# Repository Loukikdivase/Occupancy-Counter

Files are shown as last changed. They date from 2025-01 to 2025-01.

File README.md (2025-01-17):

# Occupancy Counter

by: Loukik-Sachin Divase, Rudy Marvyn Kalisetty-Appadu

**Faculty of Technology and Bionics**

***Rhine-Waal University of Applied Sciences***

Date: 16 January 2025

----

## Abstract

The occupancy counter is designed to ensure a seamless flow of people, especially on a busy day. The system tracks the number of people entering and exiting a room and can be used for libraries, offices, toilets, labs, and more. It features real-time monitoring, status indication using LEDs, compliance with safety regulations, and energy-efficient operation. A microcontroller with IR sensors detects directional movement, updates the LCD display accordingly.

## Table of Contents

- [Abstract](#abstract)
- [1 Introduction](#1-introduction)
- [2 Theory](#2-theory)
- [3 Methodology](#3-methodology)
  - [3.1 Hardware](#31-hardware)
  - [3.2 Software](#32-software)
- [4 Bill of Materials (BOM)](#4-bill-of-materials-bom)
- [5 Results](#5-results)
  - [5 Prototype](#50-prototype)
  - [5.1 Schematic](#51-schematic)
  - [5.2 Board](#52-board)
  - [5.3 UV Masking](#53-uv-masking)
  - [5.4 Etching](#54-etching)
  - [5.5 Drilling](#55-drilling)
  - [5.6 Baking](#56-baking)
  - [5.7 Testing](#57-testing)
  - [5.8 Outsourcing](#58-outsourcing)
- [6 Discussion](#6-discussion)
- [7 Conclusion](#7-conclusion)
- [8 Power Consumption](#8-power-consumption)
- [9 References](#9-references)

## 1 Introduction

Managing space efficiently in crowded environments can be challenging. The people counter helps address this issue by providing real-time tracking of room occupancy.

## 2	Theory

The occupancy counter relies on IR sensors to detect movement direction. The system uses logic to determine whether a person enters or exits, ensuring accurate count tracking. If a person passes through sensor 1(placed outside the room near the door) and sensor 2(placed inside the room near the door), the sensor will count. The sensor will increase the count by 1 if a person passes sensor 1 before sensor 2. The sensor will decrease the count by 1 if the person passes sensor 2 before sensor 1.

## 3	Methodology

### 3.1 Hardware

The system consists of:  
•	Microcontroller (ATmega328p)   
•	16MHz Crystal Oscillator  
•	Infrared LED and photodiode  
•	LCD display (16x2)  
•	Buzzer    
•	LED indicators (Red/Green/Yellow)   
•	battery  
•	Voltage regulator (LM7805)   
•	Dual Comparator (LM393)  
•	resistors  
•	capacitors  
•	inductor  
•	switches  

### 3.2 Software

•	Notepad++ for writing the main program  
•	myAVRboard MK2 for flashing the ATmega328p microcontroller  
•	The program tracks occupancy using IR sensor logic and updates the display accordingly.  

#### Code Snippets

//Reset lock for sensor 1 when signal goes HIGH  

if (sensor1_state && sensor1_locked)  
{  
     sensor1_locked = 0; //Reset lock  
}
            
//Reset lock for sensor 2 when signal goes HIGH  

if (sensor2_state && sensor2_locked)  
{  
     sensor2_locked = 0;  // Reset lock  
}  

## 4 BOM

| No. | Qty. | Manufacturer | Component | Ordering Code (Manufacturer) | Vendor | Ordering Code (Vendor) | Price per Unit (€) | Price (€) | Link |
|----|----|---|---|---|---|---|---|---|---|
| 1  | 1  | Texas Instruments | 5V Voltage Regulator SMD | LM7805MPX/NOPB | Mouser | 595-LM7805MPX/NOPB | 1.31 | 1.31 | [Link](https://www.mouser.de/ProductDetail/Texas-Instruments/LM7805MPX-NOPB?qs=gO6GG99qvRCSwIVAoVKHPw%3D%3D) |
| 2  | 4  | Atmel | ATmega328P-PU S | - | HSRW | 1712 | 2.51 | 2.51 |  |
| 3  | 4  | - | 16MHz Crystal Oscillator | QD LFXTALO03240 | Reichelt | - | 0.43 | 0.43 | [Link](https://www.reichelt.de/standardquarz-grundton-16-mhz-iqd-lfxtal003240-p245409.html?&trstct=pos_0&nbc=1) |
| 4  | 2  | - | 22pF Capacitor | RND 150MT15N2202 | Reichelt | - | 0.02 | 0.04 | [Link](https://www.reichelt.de/smd-kerko-0402-22-pf-16-v-1-mlec-rnd-150mt15n2202-p225449.html?&trstct=pos_4&nbe=1) |
| 5  | 4  | - | 10k Ohm Resistor | - | HSRW | 621 | 0.01 | 0.04 | [Link](https://ee.hsrw.org/) |
| 6  | 2  | Vishay/BC Components | 220uF Capacitor, 10V DC | MAL214097403E3 | Mouser | 594-MAL214097403E3 | 1.97 | 3.94 | [Link](https://www.mouser.de/ProductDetail/Vishay-BC-Components/MAL214097403E3?qs=aJI9t0tCUIVP9cSclwINCQ%3D%3D) |
| 7  | 5  | - | LEDs | - | HSRW | 471,497,498 | 0.06 | 0.24 | [Link](https://ee.hsrw.org/) |
| 8  | 7  | - | 220 Ohm Resistor | - | HSRW | 579 | 0.01 | 0.07 | [Link](https://ee.hsrw.org/) |
| 9  | 1  | - | LCD Display 16x2 | DEBO LCD16X2 BL | Reichelt | - | 4.65 | 4.65 | [Link](https://www.reichelt.de/entwicklerboards-display-16-x-2-zeichen-blau-debo-led16x2-bl-p335002.html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) |
| 10 | 1  | - | 28-Pin IC Socket | - | HSRW | 630 | 0.21 | 0.21 | [Link](https://ee.hsrw.org/) |
| 11 | 2  | - | Push Button | TASTER 9305 | Reichelt | - | 0.20 | 0.40 | [Link](https://www.reichelt.de/kurzhubtaster-6x6mm-hoehe-8-Omm-12v-vertikal-taster-9305-p44586.html) |
| 12 | 2  | Everlight | Infrared Diode (940nm, emitter) | IR 7373C EVL | Reichelt | - | 0.15 | 0.30 | [Link](https://www.reichelt.de/infrarot-diode-gaalas-940-nm-50-5-mm-t-1-3-4-ir-7373c-evl-p219706.html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) |
| 13 | 6  | - | 0.1µF Capacitor SM | 0.1/63RAD | HSRW | 372 | 0.03 | 0.18 | [Link](https://ee.hsrw.org/) |
| 14 | 2  | Vishay | Phototransistor (Receiver) | BPV10NF | Reichelt | - | 0.35 | 0.70 | [Link](https://www.reichelt.de/pin-fotodiode-5mm-tageslichfilter-20-60-a-870-950nm-bpv-10nf-p146650.html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) |
| 15 | 4  | Aragonesa de Components | Potentiometer (10k Ohm) | ACP 6-S 10K | Reichelt | - | 0.21 | 0.84 | [Link](https://www.reichelt.de/einstellpotentiometer-stehend-10-kohm-6-mm-acp-6-s-10k-p110242.html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) |
| 16 | 1  | STMicroelectronics | LM393 Comparator | LM393 D STM | Reichelt | - | 0.21 | 0.21 | [Link](https://www.reichelt.de/komparator-18v-36v-2-fach-so-8-lm-393-d-stm-p348702.html?&trstct=pos_O&nbe=1) |
| 17 | 1  | - | 2-Pin Angled Connector (Male) | PSS 254/3W | Reichelt | - | 0.06 | 0.06 | [Link](https://www.reichelt.de/printstecker-einzelstecker-gewinkelt-3-polig-pss-254-3w-p14910.html) |
| 18 | 1  | OURNS | 10µH Inductor, 10% Tolerance | CC453232A-100KL | Mouser | 652-CC453232A-100KL | 0.47 | 0.47 | [Link](https://www.mouser.de/ProductDetail/Bourns/CC453232A-100KL?qs=sPbYRqrBIVk4tmhOTVDWBA%3D%3D) |
| 19 | 1  | - | Battery | - | HSRW | - | 1.00 | 1.00 | [Link](https://ee.hsrw.org/) |
| 20 | 1  | - | 3-Pin Switch | - | HSRW | - | 1.35 | 1.35 | [Link](https://ee.hsrw.org/) |
| 21 | 1  | - | Male Headers | - | HSRW | - | 1.00 | 1.00 | [Link](https://ee.hsrw.org/) |
| 22 | 1  | - | Buzzer | - | HSRW | - | 0.50 | 0.50 | [Link](https://ee.hsrw.org/) |
| 23 | 1  | - | NPN Transistor BC547 | - | HSRW | - | 0.36 | 0.36 | [Link](https://ee.hsrw.org/) |

## 5	Results

### Prototype

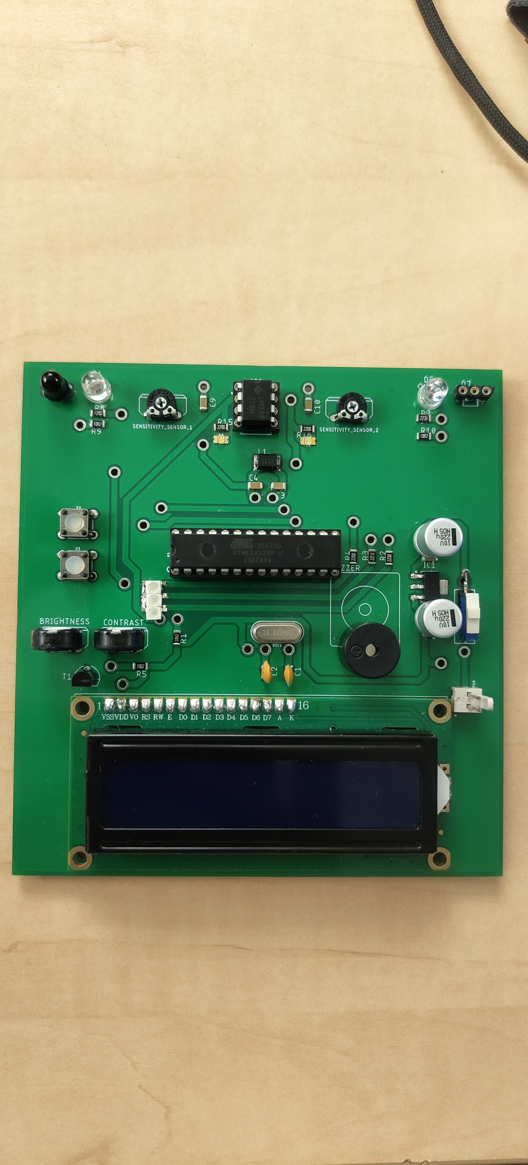
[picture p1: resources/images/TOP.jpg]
TOP


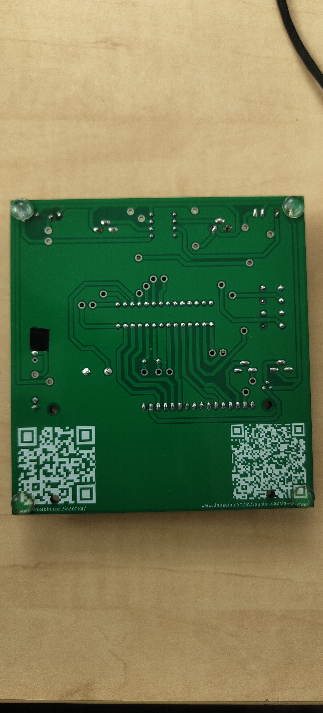
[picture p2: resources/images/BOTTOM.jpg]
BOTTOM


### 5.1 Schematic

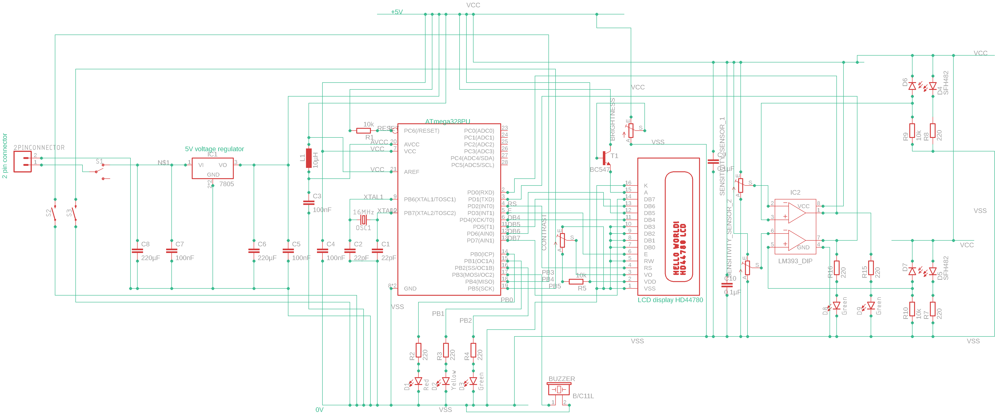
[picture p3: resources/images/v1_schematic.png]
Schematic


### 5.2 board

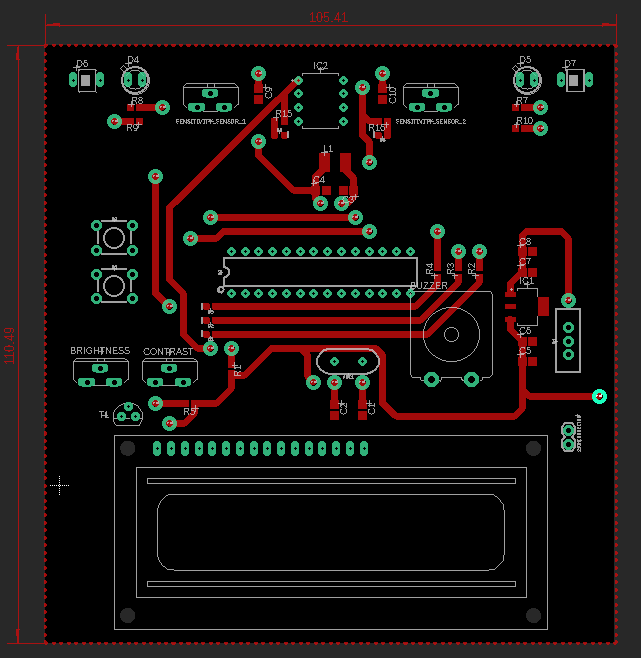
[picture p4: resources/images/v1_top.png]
top


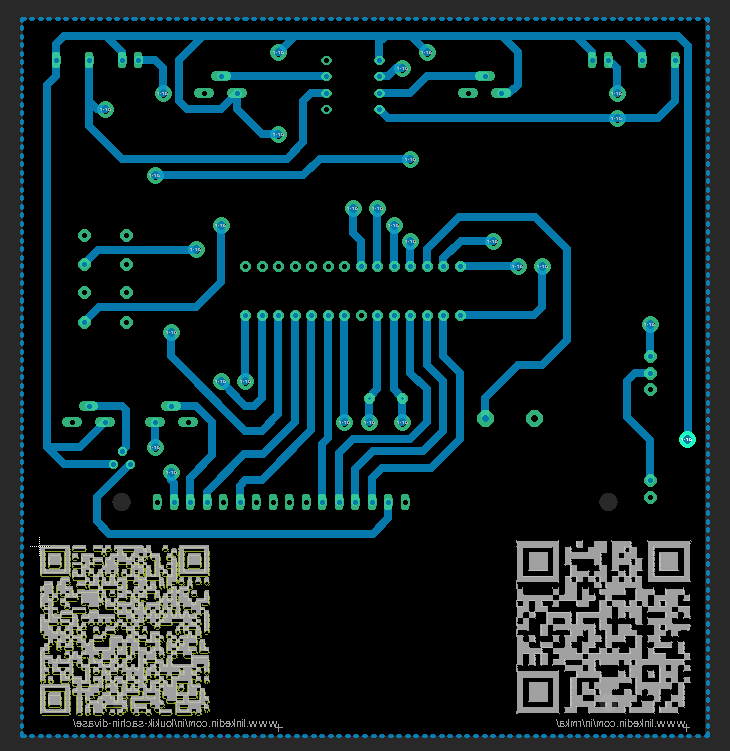
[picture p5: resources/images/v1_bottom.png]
bottom


### 5.3 UV Masking

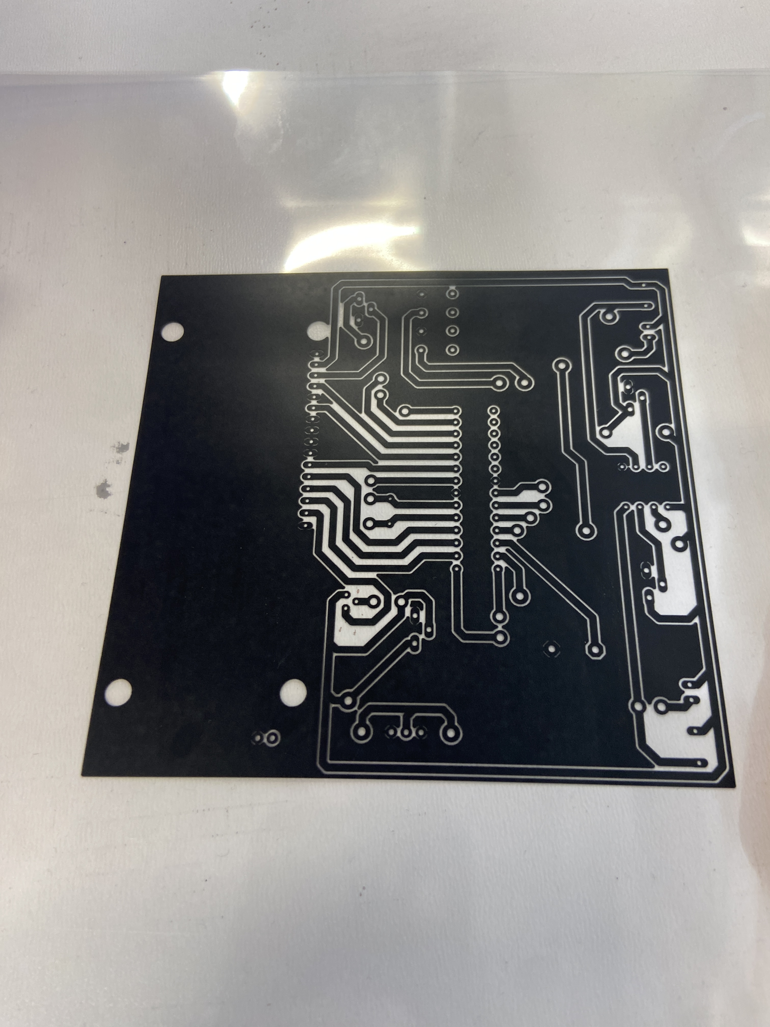
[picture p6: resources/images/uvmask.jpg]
uvmask


### 5.4 Etching

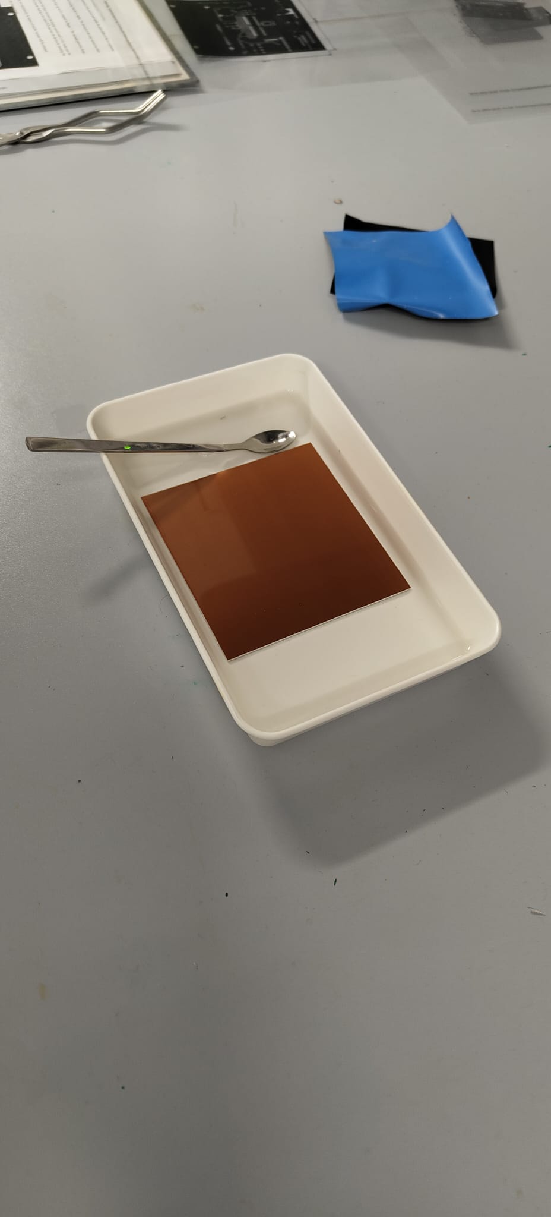
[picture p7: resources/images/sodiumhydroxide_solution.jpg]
sodiumhydroxide_solution


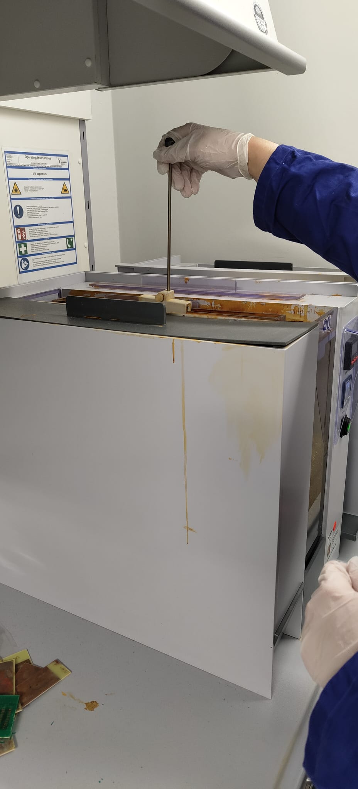
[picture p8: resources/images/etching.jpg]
etching


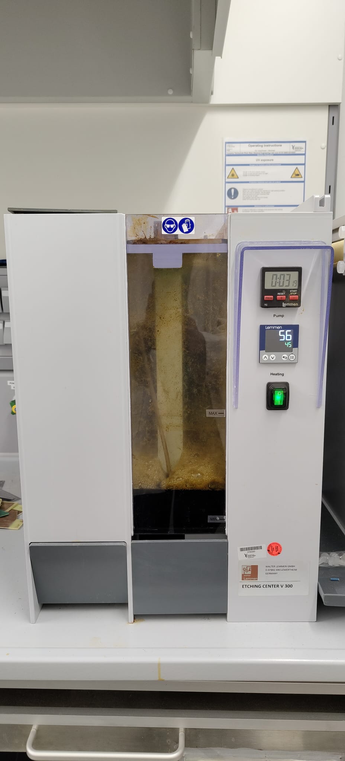
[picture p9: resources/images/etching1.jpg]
etching1


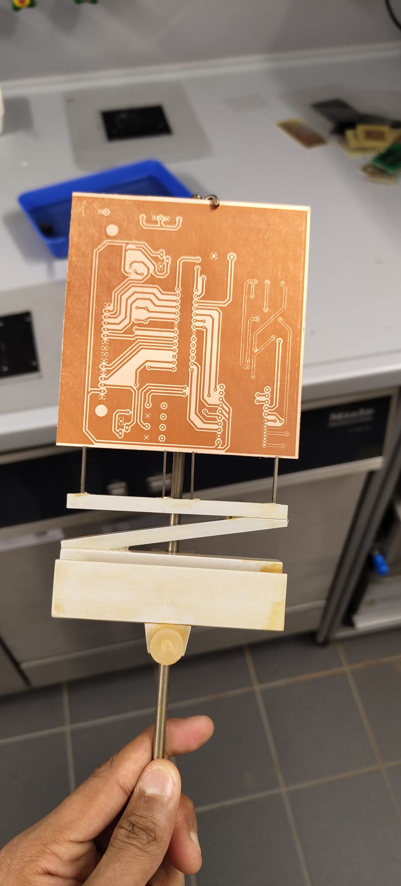
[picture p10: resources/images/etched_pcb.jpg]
etched_pcb


### 5.5 Drilling

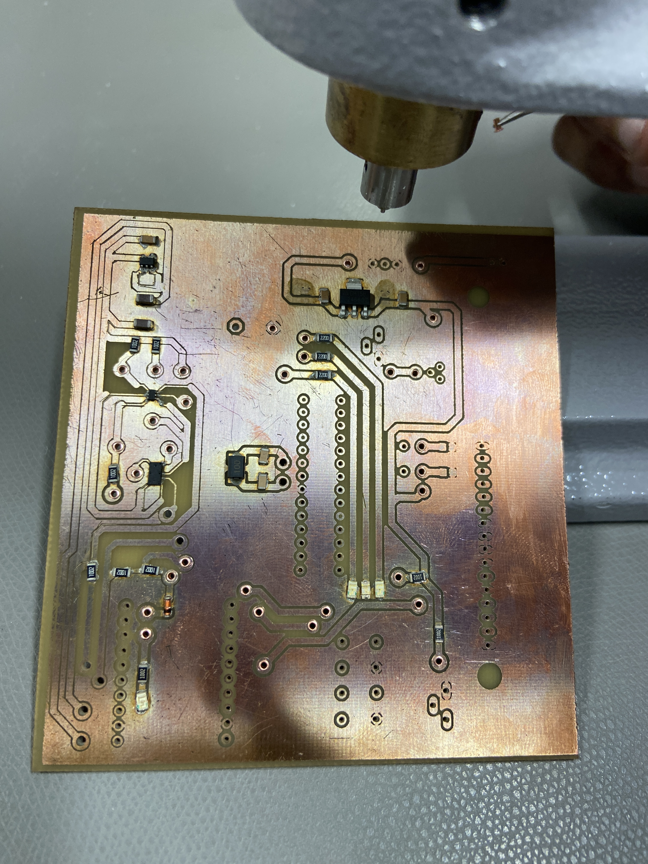
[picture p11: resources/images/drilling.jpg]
drilling


### 5.6 Baking

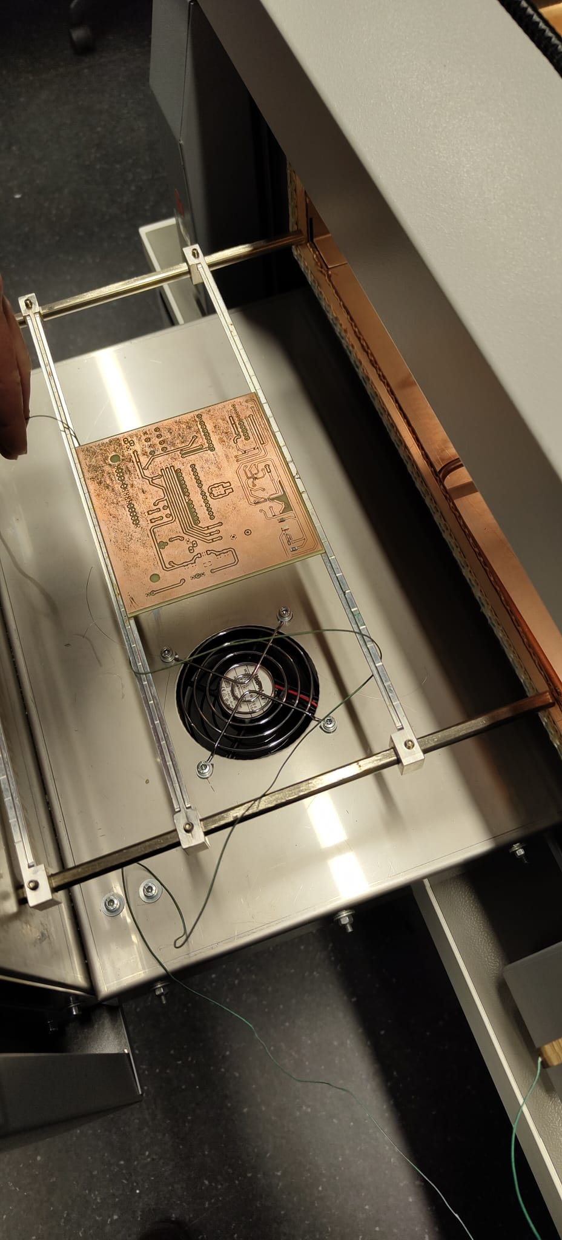
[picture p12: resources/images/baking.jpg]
baking


### 5.7 Testing

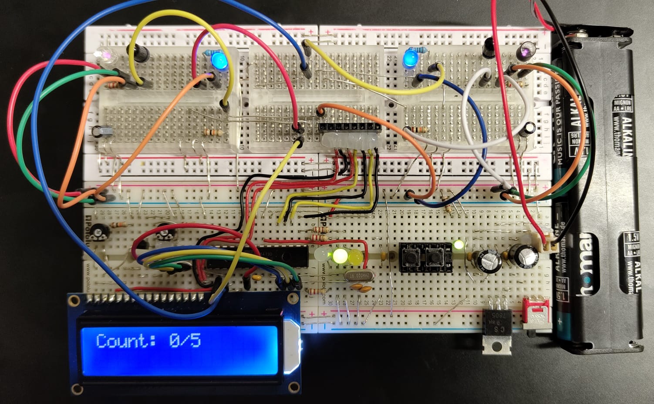
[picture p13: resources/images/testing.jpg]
testing


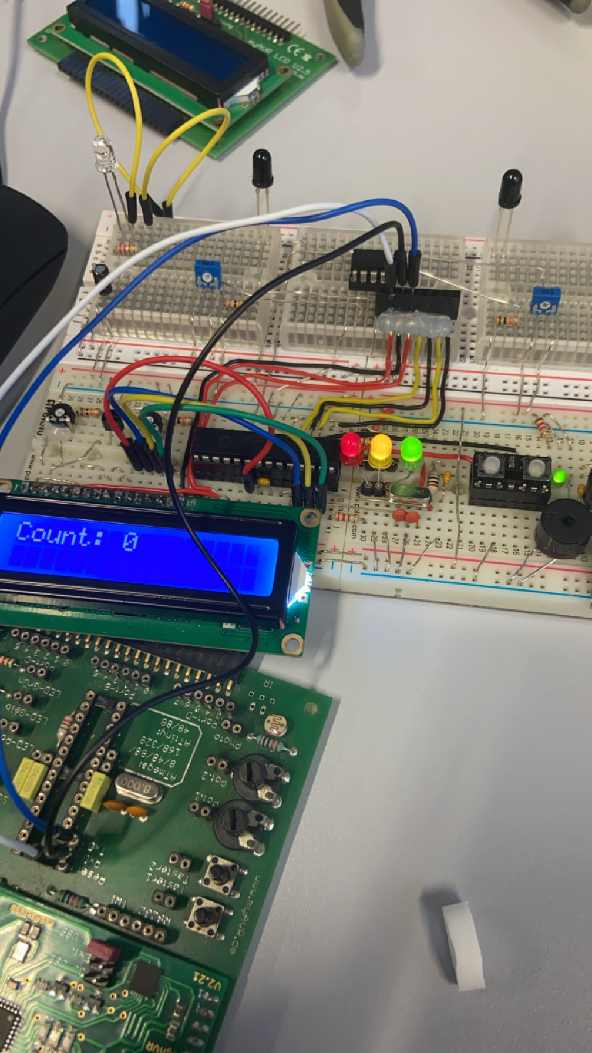
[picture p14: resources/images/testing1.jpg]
testing1


### 5.8 Outsourcing

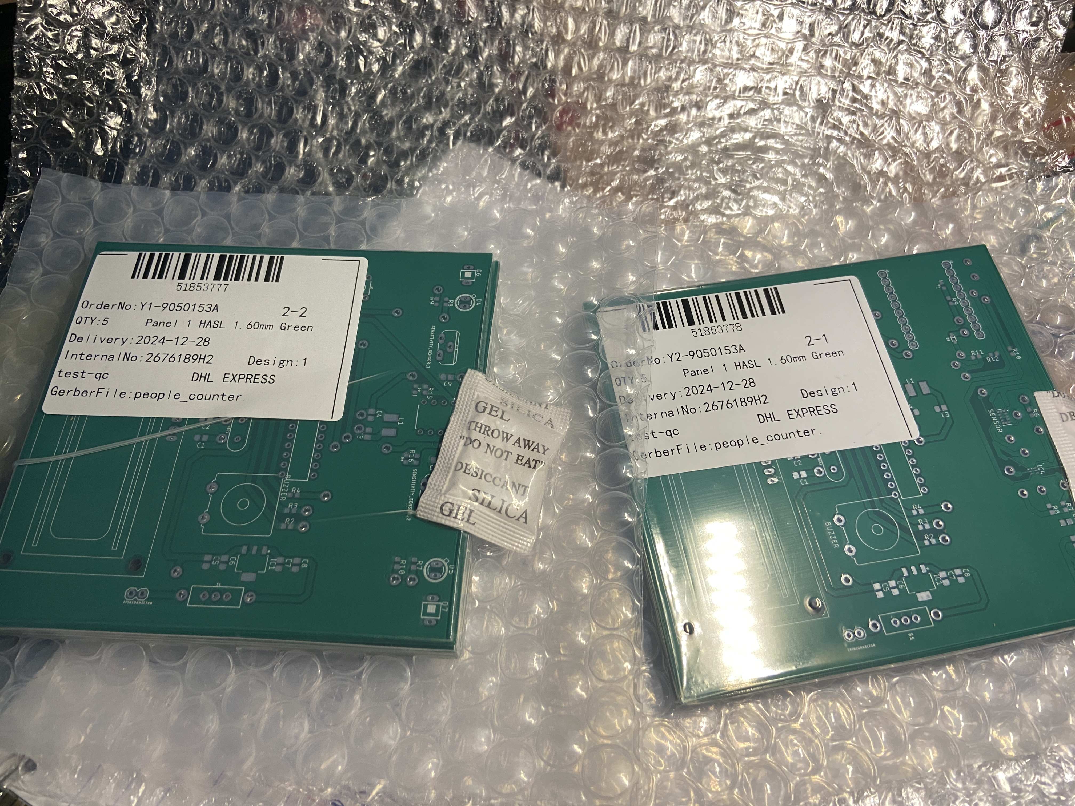
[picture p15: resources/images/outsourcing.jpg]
outsourcing


## version 2 (additional)

### Schematic

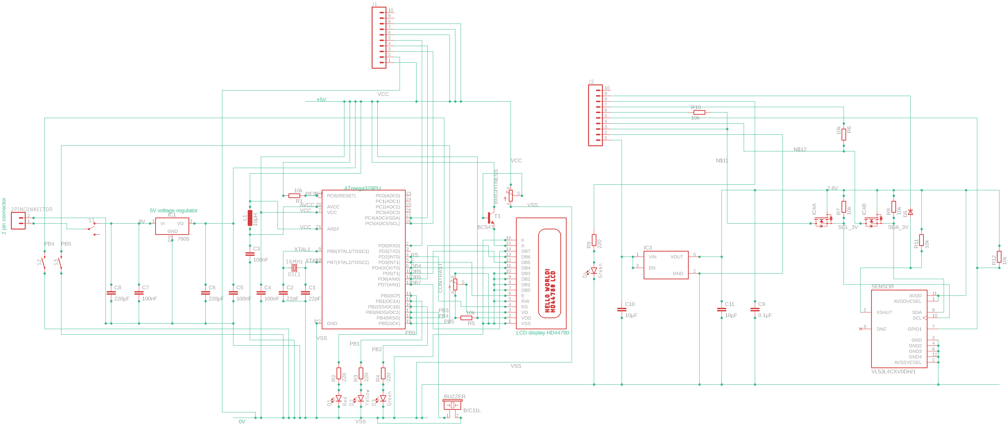
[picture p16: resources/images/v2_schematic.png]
v2_Schematic


### Board

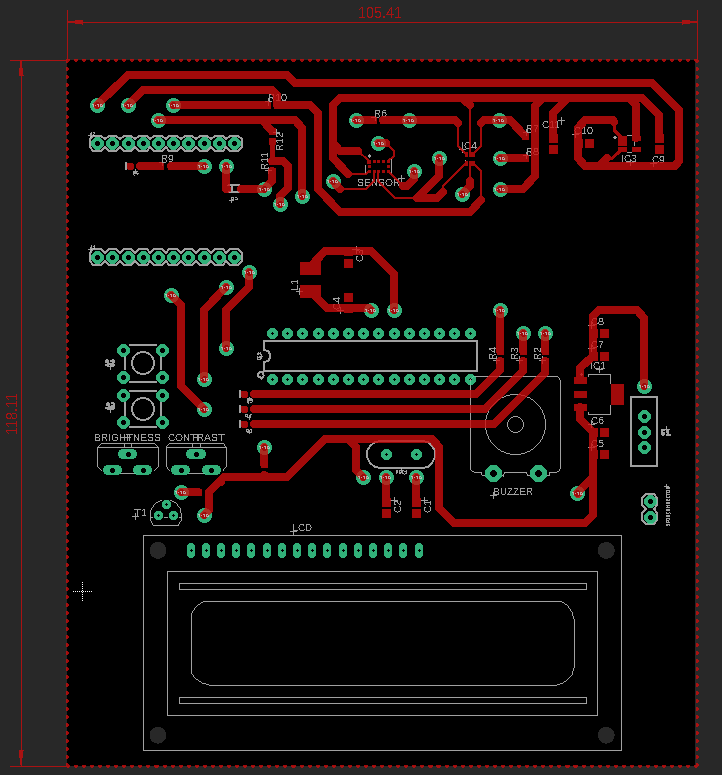
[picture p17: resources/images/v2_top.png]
v2_top


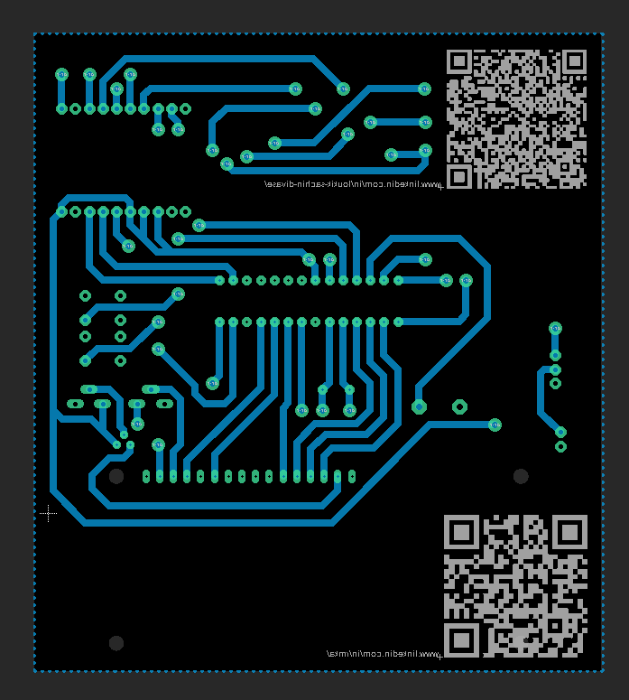
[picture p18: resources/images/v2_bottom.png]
v2_bottom


## 6	Discussion

The system performs well in controlled conditions. However, environmental factors such as lighting variations may affect sensor accuracy. Calibration is necessary for optimal performance.

What exactly happens? 
The person must pass both sensors to register the count since our product is directional.

## 7	Conclusion

As aspiring engineers, we believe that this project was a success. However, there might be some unsolved challenges that we did not encounter, and we would be more than happy to address them in the future. Future work could involve integrating wireless data transmission for monitoring remotely.

## 8	Power Consumption

Total power consumption: 1.29W, where V = 6V and I = 0.22A

Actual useful power consumption: 1W,  where V = 4.85V and I = 0.21A.

## 9	References

* [1] https://shop.myavr.de/Systemboards%20und%20Programmer/myAVR%20Board%20MK2,%20best%C3%BCckt.htm?sp=article.sp.php&artID=40

* [2] https://docs.arduino.cc/hardware/uno-rev3/

* [3] https://github.com/Loukikdivase/Occupancy-Counter/tree/main/resources

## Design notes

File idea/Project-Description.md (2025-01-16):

# Project title
	- Occupancy counter
	
## Project overview
	- The occupancy counter is designed to keep seemless flow whenever there's a high increase in people on a busy day. 
	- Also, the system is designed to track the number of people entering and exiting a room.
	- This type of system is beneficial for library, offices, toilets, labs, etc. 

### Main features

	• Room management: 
	- By providing real-time data on room occupancy, this system helps in managing room usage.
	
	• Status LED: 
	- Whenever the room is full, the status LED - Red LED will light on depending on the number of spaces being occupied inside. 
	For example:
	
	- Red LED: if there's no spot available inside, the red LED will light up, meaning that no one can enter the room.
	
	- Green LED: if there's 1 spot available, the green LED will light up, meaning that another person can use the room. (optional)
	
	- Yellow LED: if there's 0 spot available, the yellow LED will light up.
	
	• Safety: 
	- In environments, like small labs, there may be occupancy limits for safety regulations.
	- This system helps ensure compliance by allowing managers to check and control room capacity.
	
	• Energy efficient:
	- By tracking room usage, the system can be paired with automated lighting, ensuring energy only gets used when people are present, reducing unnecessary consumption.
	
	• Battery:
	- The system will be fully powered using a 9V lithium battery which should last long enough before the next battery change.
 
	• IR proximity sensor:
	- Whenever someone passes through the main room door, the sensor 1 will automatically detect someone's presence and register the count as one person inside.
	- By using two IR sensors placed in sequence, the system detects the direction of movement. 
	- If the first sensor triggers before the second, it records an entry; if the second triggers before the first, it records an exit. 
	- This directional detection minimises errors, providing reliable, correct counts.
 
	• LCD display:
	- A LCD display is used to show how many spaces in realtime are being occupied inside the room.
	- This makes it easy for its users to know how many people are present without needing to enter the room or manually count.
 
	• Buzzer: 
	- When the washroom is full, the buzzer will produce a sound at a certain frequency so that you know it's full and can not enter immediately.
	
	• Cost effective: 
	- As the components are readily available.
	
#### Main components

	• Microcontroller (ATmega328p)
	• Infra red LED
	• Photodiode
	• LCD display (16 x 2)
	• Capacitors
	• Lithium battery (9V)
	• Buzzer
	• LEDs (Red/Green/Yellow/Blue)
	• 16 MHz crystal oscillator
	• Resistors
	• Pull up resistors
	• Push buttons
	• 28-pin IC socket
	• Voltage regulator (LM7805_smd)
	• Inductor
	• Potentiometers
	• 2-pin connector
	• Dual comparator (LM393)
	• Jumpers
	• Switch
	• Bipolar Junction Transistor (BC547C)
	
##### Programming

	• Notepad ++ will be used to write the main.c file.
	• The microcontroller (ATmega328p) will be flashed using myAVRboard MK2.

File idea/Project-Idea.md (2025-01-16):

# Our project idea is:

	• That the system will use a microcontroller and 2 IR sensors to detect directional movement through a door and updates an on-screen counter accordingly. 
	• The counter, displayed on an LCD display will provide a real-time count on occupancy making it easy to check room usage.
	• It will provide, Knowing the occupancy would help in managing the space efficiently.

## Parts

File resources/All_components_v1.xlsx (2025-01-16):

Components | Values for resistors (R1 - R11), potentiometers (P1 - P4) in Ohms , capacitors (C1 - C10) in Fahrrad, inductor in Henry, oscillators in Hz and battery/cell in V | Remarks | Status
R1 | 10k | Ordered | In use
R2 | 220 | Ordered | In use
R3 | 220 | Ordered | In use
R4 | 220 | Ordered | In use
R5 | 10k | Ordered | In use
R6 | 220 | Ordered | In use
R7 | 220 | Ordered | In use
R8 | 220 | Ordered | In use
R9 | 220 | Ordered | In use
R10 | 10k | Ordered | In use
R11 | 10k | Ordered | In use
C1 | 22p | Ordered | In use
C2 | 22p | Ordered | In use
C3 | 100n | Ordered | In use
C4 | 100n | Ordered | In use
C5 | 100n | Ordered | In use
C6 | 220u | Ordered | In use
C7 | 100n | Ordered | In use
C8 | 220u | Ordered | In use
C9 | 0.1u | Ordered | In use
C10 | 0.1u | Ordered | In use
D1 (IN4001) |  | Ordered | In use
D1 | Red | Ordered | In use
D2 | Yellow | Ordered | In use
D3 | Green | Ordered | In use
D4 | IR (infra red - emitter) - transparent | Ordered | In use
D5 | PT (Photo transistor - receiver) - black | Ordered | In use
D6 | IR (infra red - emitter) - transparent | Ordered | In use
D7 | PT (Photo transistor - receiver) - black | Ordered | In use
D8 | Blue | Ordered | In use
D9 | Blue | Ordered | In use
IC1 | 5V voltage regulator (TS 7805) | Ordered | In use
IC2 | Atmega328P | Ordered | In use
IC3 | LM393 | Ordered | In use
L1 | 10u | Ordered | In use
T1 | NPN transistor | Ordered | In use
S1 | 3 pins switch | Ordered | In use
LCD 16 x 2 (HD44780) |  | Ordered | In use
Potentiometer (for contrast on the LCD screen) | 10k | Ordered | In use
Potentiometer (for brightness on the LCD screen) | 10k | Ordered | In use
Potentiometer (for sensitivity for the IR sensor 1) | 10k | Ordered | In use
Potentiometer (for sensitivity for the IR sensor 2) | 10k | Ordered | In use
Crystal oscillator (Osc1) | 16M | Ordered | In use
2 pins straight connector (for battery) |  | Ordered | In use
Push buttons 1 |  | Ordered | In use
Push buttons 2 |  | Ordered | In use
28-Pin socket for the chip |  | Ordered | In use
USB 2.0 type B mini socket (female) |  | Ordered | not in use
Buzzer |  | Ordered | In use

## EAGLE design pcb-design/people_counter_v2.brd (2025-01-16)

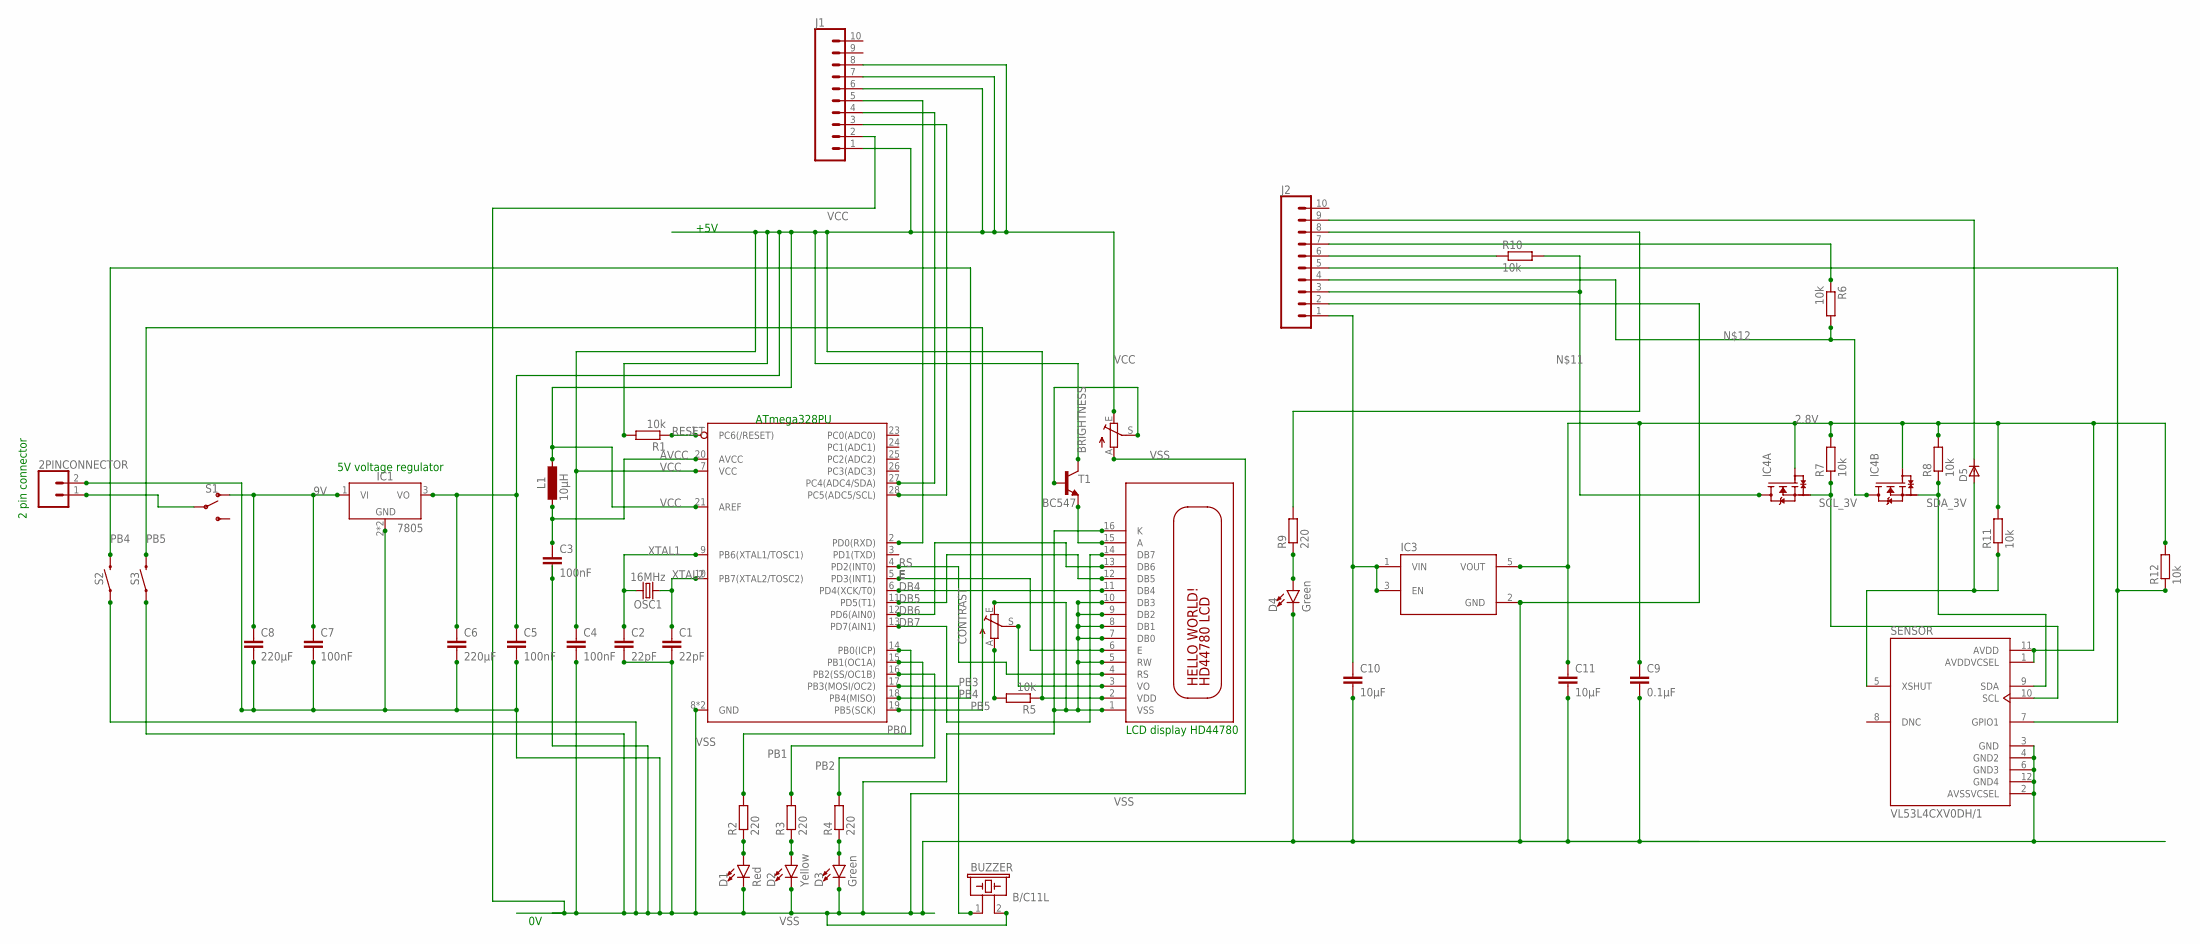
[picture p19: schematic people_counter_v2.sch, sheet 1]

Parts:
2PINCONNECTOR: CONN_02; 1X02
BRIGHTNESS: TRIM_EU-PT10S; PT-10S
BUZZER: B/C11L
C1, C2: 22pF; C0805
C3, C4, C5, C7: 100nF; C0805
C6, C8: 220µF; C0805
C9: 0.1µF; C0805
C10, C11: 10µF; C0805
CONTRAST: TRIM_EU-PT10S; PT-10S
D1: Red; LED-0603
D2: Yellow; LED-0603
D3, D4: Green; LED-0603
D5: 1N4148WS; SOD323F
IC1: 7805; SOT230P700X170-4
IC2: 328P; DIP28
IC3: MIC5504-2.8YM5-TR; SOT95P280X145-5N
IC4: DMN63D8LDW-7; SOT363
J1, J2: CONN_10"; 1X10
L1: 10µH; L1812
OSC1: 16MHz; HC49US
R1, R5, R6, R7, R8, R10, R11, R12: 10k; R0603
R2, R3, R4, R9: 220; R0603
S1: SWITCH-SPDT-PTH-11.6X4.0MM; SWITCH_SPDT_PTH_11.6X4.0MM
S2, S3: MOMENTARY-SWITCH-SPST-PTH-6.0MM; TACTILE_SWITCH_PTH_6.0MM
SENSOR: VL53L4CXV0DH/1; XCDR_VL53L4CXV0DH/1
T1: BC547; TO92
X1: HD44780LCD-1602; LCD1602

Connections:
2.8V: C9.1, C11.1, IC3.5 (VOUT), IC4.G1 (G), IC4.G2 (G), R7.2, R8.2, R11.2, R12.2, SENSOR.1 (AVDDVCSEL), SENSOR.11 (AVDD)
9V: C7.1, C8.1, IC1.1 (VI), S1.1 (O)
AVCC: C3.1, IC2.20 (AVCC), L1.2
DB4: IC2.6 (PD4(XCK/T0)), X1.11 (DB4)
DB5: IC2.11 (PD5(T1)), X1.12 (DB5)
DB6: IC2.12 (PD6(AIN0)), X1.13 (DB6)
DB7: IC2.13 (PD7(AIN1)), X1.14 (DB7)
E: IC2.5 (PD3(INT1)), X1.6 (E)
GREEN: D3.A, R4.1
unnamed: J2.6, R10.1
unnamed: D4.A, R9.1
unnamed: D5.C, J2.9
unnamed: 2PINCONNECTOR.1, S1.2
unnamed: IC2.2 (PD0(RXD)), J1.5
unnamed: D5.A, R11.1, SENSOR.5 (XSHUT)
unnamed: CONTRAST.A, R5.2
unnamed: J2.5, R12.1, SENSOR.7 (GPIO1)
unnamed: IC4.D1 (D), J2.3, R10.2
unnamed: IC4.D2 (D), J2.4, R6.2
unnamed: BRIGHTNESS.S, T1.2 (B)
unnamed: J2.8, R9.2
unnamed: J2.7, R6.1
unnamed: C10.1, IC3.1 (VIN), IC3.3 (EN), J2.1
unnamed: T1.1 (E), X1.15 (A)
PB0: IC2.14 (PB0(ICP)), R2.2
PB1: IC2.15 (PB1(OC1A)), R3.2
PB2: IC2.16 (PB2(SS/OC1B)), R4.2
PB3: BUZZER.1, IC2.17 (PB3(MOSI/OC2))
PB4: IC2.18 (PB4(MISO)), S2.3 (2)
PB5: IC2.19 (PB5(SCK)), S3.3 (2)
RED: D1.A, R2.1
RESET: IC2.1 (PC6(/RESET)), R1.1
RS: IC2.4 (PD2(INT0)), X1.4 (RS)
SCL_3V: IC4.S1 (S), R7.1, SENSOR.10 (SCL)
SCL_5V: IC2.28 (PC5(ADC5/SCL)), J1.3
SDA_3V: IC4.S2 (S), R8.1, SENSOR.9 (SDA)
SDA_5V: IC2.27 (PC4(ADC4/SDA)), J1.4
VCC: BRIGHTNESS.E, C4.1, C5.1, C6.1, IC1.3 (VO), IC2.7 (VCC), IC2.21 (AREF), J1.1, J1.6, J1.7, J1.8, L1.1, R1.2, R5.1, T1.3 (C), X1.2 (VDD)
VO: CONTRAST.S, X1.3 (VO)
VSS: 2PINCONNECTOR.2, BRIGHTNESS.A, BUZZER.2, C1.2, C2.2, C3.2, C4.2, C5.2, C6.2, C7.2, C8.2, C9.2, C10.2, C11.2, CONTRAST.E, D1.C, D2.C, D3.C, D4.C, IC1.2 (GND), IC1.4 (GND), IC2.8 (GND), IC2.22 (GND), IC3.2 (GND), J1.2, J2.2, S2.1, S3.1, SENSOR.2 (AVSSVCSEL), SENSOR.3 (GND), SENSOR.4 (GND2), SENSOR.6 (GND3), SENSOR.12 (GND4), X1.1 (VSS), X1.5 (RW), X1.7 (DB0), X1.8 (DB1), X1.9 (DB2), X1.10 (DB3), X1.16 (K)
XTAL1: C2.1, IC2.9 (PB6(XTAL1/TOSC1)), OSC1.2
XTAL2: C1.1, IC2.10 (PB7(XTAL2/TOSC2)), OSC1.1
YELLOW: D2.A, R3.1

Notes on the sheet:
5V voltage regulator
2 pin connector
+5V
ATmega328PU
LCD display HD44780

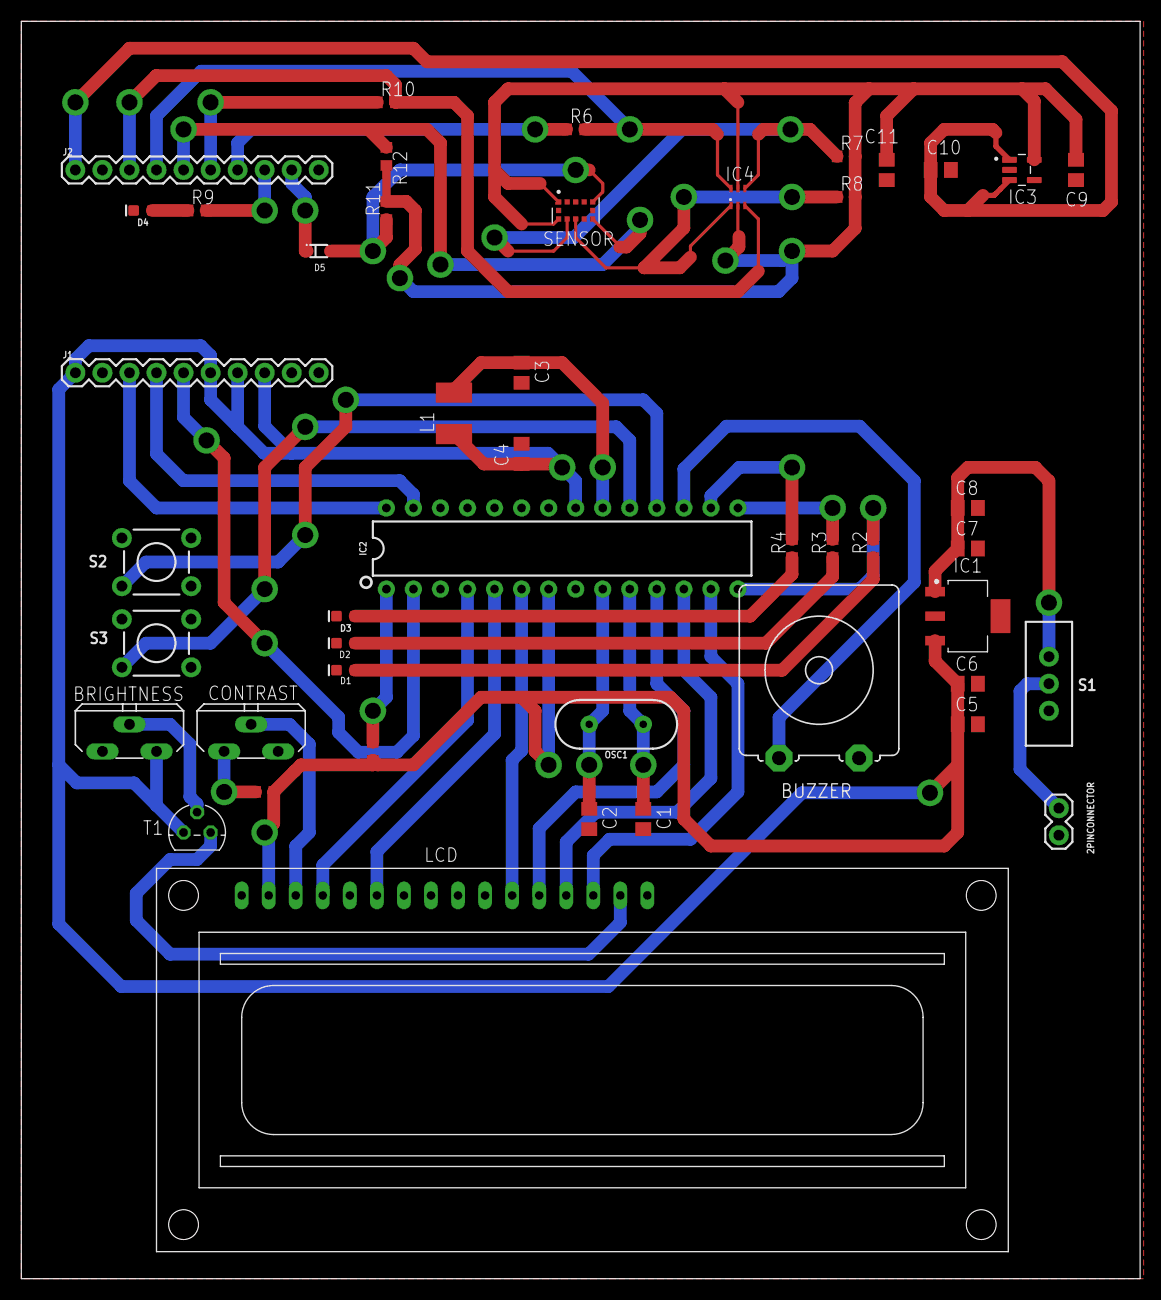
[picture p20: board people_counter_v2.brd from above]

Board: 2 copper layers, 105.1 x 118.1 mm, 46 parts (0 on the bottom side), 43 nets.

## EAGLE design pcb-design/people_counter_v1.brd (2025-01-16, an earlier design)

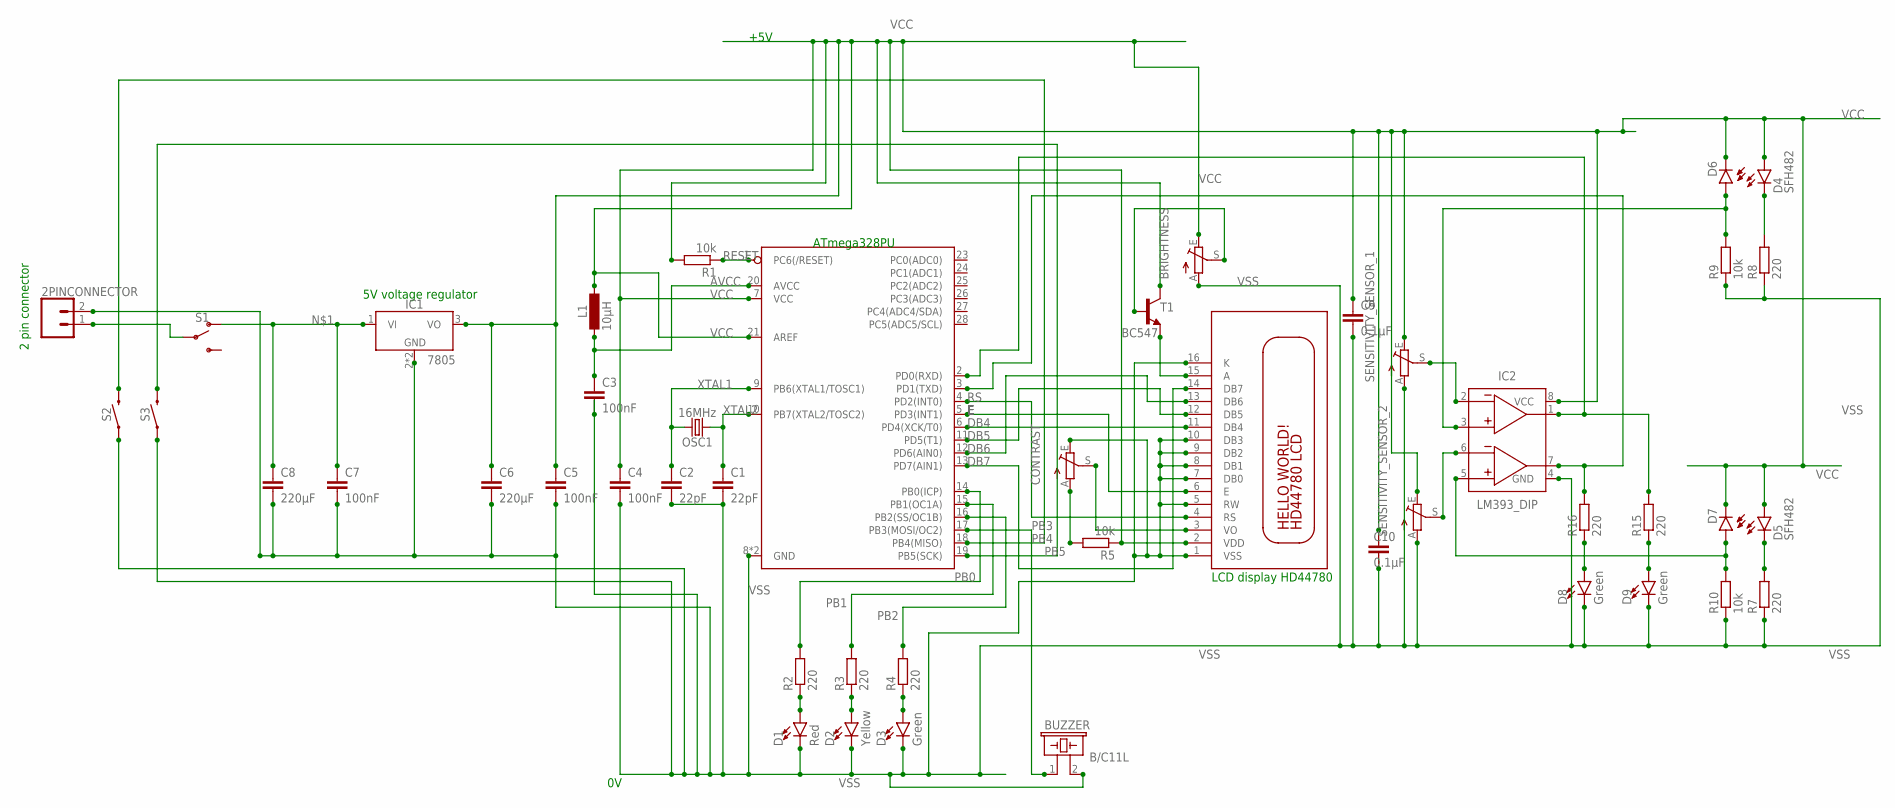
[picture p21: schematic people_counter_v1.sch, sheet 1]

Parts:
2PINCONNECTOR: CONN_02; 1X02
BRIGHTNESS: TRIM_EU-PT10S; PT-10S
BUZZER: B/C11L
C1, C2: 22pF; C0805
C3, C4, C5, C7: 100nF; C0805
C6, C8: 220µF; C0805
C9, C10: 0.1µF; C0805
CONTRAST: TRIM_EU-PT10S; PT-10S
D1: Red; LED-0603
D2: Yellow; LED-0603
D3, D8, D9: Green; LED-0603
D4, D5: SFH482
D6, D7: BP104
IC1: 7805; SOT230P700X170-4
IC2: LM393_DIP; DIP826W53P254L959H508Q8B
L1: 10µH; L1812
OSC1: 16MHz; HC49US
R1, R5, R9, R10: 10k; R0603
R2, R3, R4, R7, R8, R15, R16: 220; R0603
S1: SWITCH-SPDT-PTH-11.6X4.0MM; SWITCH_SPDT_PTH_11.6X4.0MM
S2, S3: MOMENTARY-SWITCH-SPST-PTH-6.0MM; TACTILE_SWITCH_PTH_6.0MM
SENSITIVITY_SENSOR_1, SENSITIVITY_SENSOR_2: TRIM_EU-PT10S; PT-10S
T1: BC547; TO92
U1: 328P; DIP28
X1: HD44780LCD-1602; LCD1602

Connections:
AVCC: C3.1, L1.2, U1.20 (AVCC)
DB4: U1.6 (PD4(XCK/T0)), X1.11 (DB4)
DB5: U1.11 (PD5(T1)), X1.12 (DB5)
DB6: U1.12 (PD6(AIN0)), X1.13 (DB6)
DB7: U1.13 (PD7(AIN1)), X1.14 (DB7)
E: U1.5 (PD3(INT1)), X1.6 (E)
unnamed: C7.1, C8.1, IC1.1 (VI), S1.1 (O)
unnamed: BRIGHTNESS.S, T1.2 (B)
unnamed: 2PINCONNECTOR.1, S1.2
unnamed: D1.A, R2.1
unnamed: D2.A, R3.1
unnamed: CONTRAST.A, R5.2
unnamed: D3.A, R4.1
unnamed: D6.A, IC2.3 (+IN1), R9.2
unnamed: D7.A, IC2.5 (+IN2), R10.2
unnamed: D5.K (C), R7.2
unnamed: D4.K (C), R8.2
unnamed: IC2.1 (OUT1), R15.2, U1.2 (PD0(RXD))
unnamed: IC2.7 (OUT2), R16.2, U1.3 (PD1(TXD))
unnamed: IC2.2 (-IN1), SENSITIVITY_SENSOR_1.S
unnamed: IC2.6 (-IN2), SENSITIVITY_SENSOR_2.S
unnamed: T1.1 (E), X1.15 (A)
unnamed: D9.A, R15.1
unnamed: D8.A, R16.1
PB0: R2.2, U1.14 (PB0(ICP))
PB1: R3.2, U1.15 (PB1(OC1A))
PB2: R4.2, U1.16 (PB2(SS/OC1B))
PB3: BUZZER.1, U1.17 (PB3(MOSI/OC2))
PB4: S2.3 (2), U1.18 (PB4(MISO))
PB5: S3.3 (2), U1.19 (PB5(SCK))
RESET: R1.1, U1.1 (PC6(/RESET))
RS: U1.4 (PD2(INT0)), X1.4 (RS)
VCC: BRIGHTNESS.E, C4.1, C5.1, C6.1, C9.1, C10.1, D4.A, D5.A, D6.K (C), D7.K (C), IC1.3 (VO), IC2.8 (VCC), L1.1, R1.2, R5.1, SENSITIVITY_SENSOR_1.E, SENSITIVITY_SENSOR_2.E, T1.3 (C), U1.7 (VCC), U1.21 (AREF), X1.2 (VDD)
VO: CONTRAST.S, X1.3 (VO)
VSS: 2PINCONNECTOR.2, BRIGHTNESS.A, BUZZER.2, C1.2, C2.2, C3.2, C4.2, C5.2, C6.2, C7.2, C8.2, C9.2, C10.2, CONTRAST.E, D1.C, D2.C, D3.C, D8.C, D9.C, IC1.2 (GND), IC1.4 (GND), IC2.4 (GND), R7.1, R8.1, R9.1, R10.1, S2.1, S3.1, SENSITIVITY_SENSOR_1.A, SENSITIVITY_SENSOR_2.A, U1.8 (GND), U1.22 (GND), X1.1 (VSS), X1.5 (RW), X1.7 (DB0), X1.8 (DB1), X1.9 (DB2), X1.10 (DB3), X1.16 (K)
XTAL1: C2.1, OSC1.2, U1.9 (PB6(XTAL1/TOSC1))
XTAL2: C1.1, OSC1.1, U1.10 (PB7(XTAL2/TOSC2))

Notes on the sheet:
5V voltage regulator
2 pin connector
+5V
ATmega328PU
LCD display HD44780

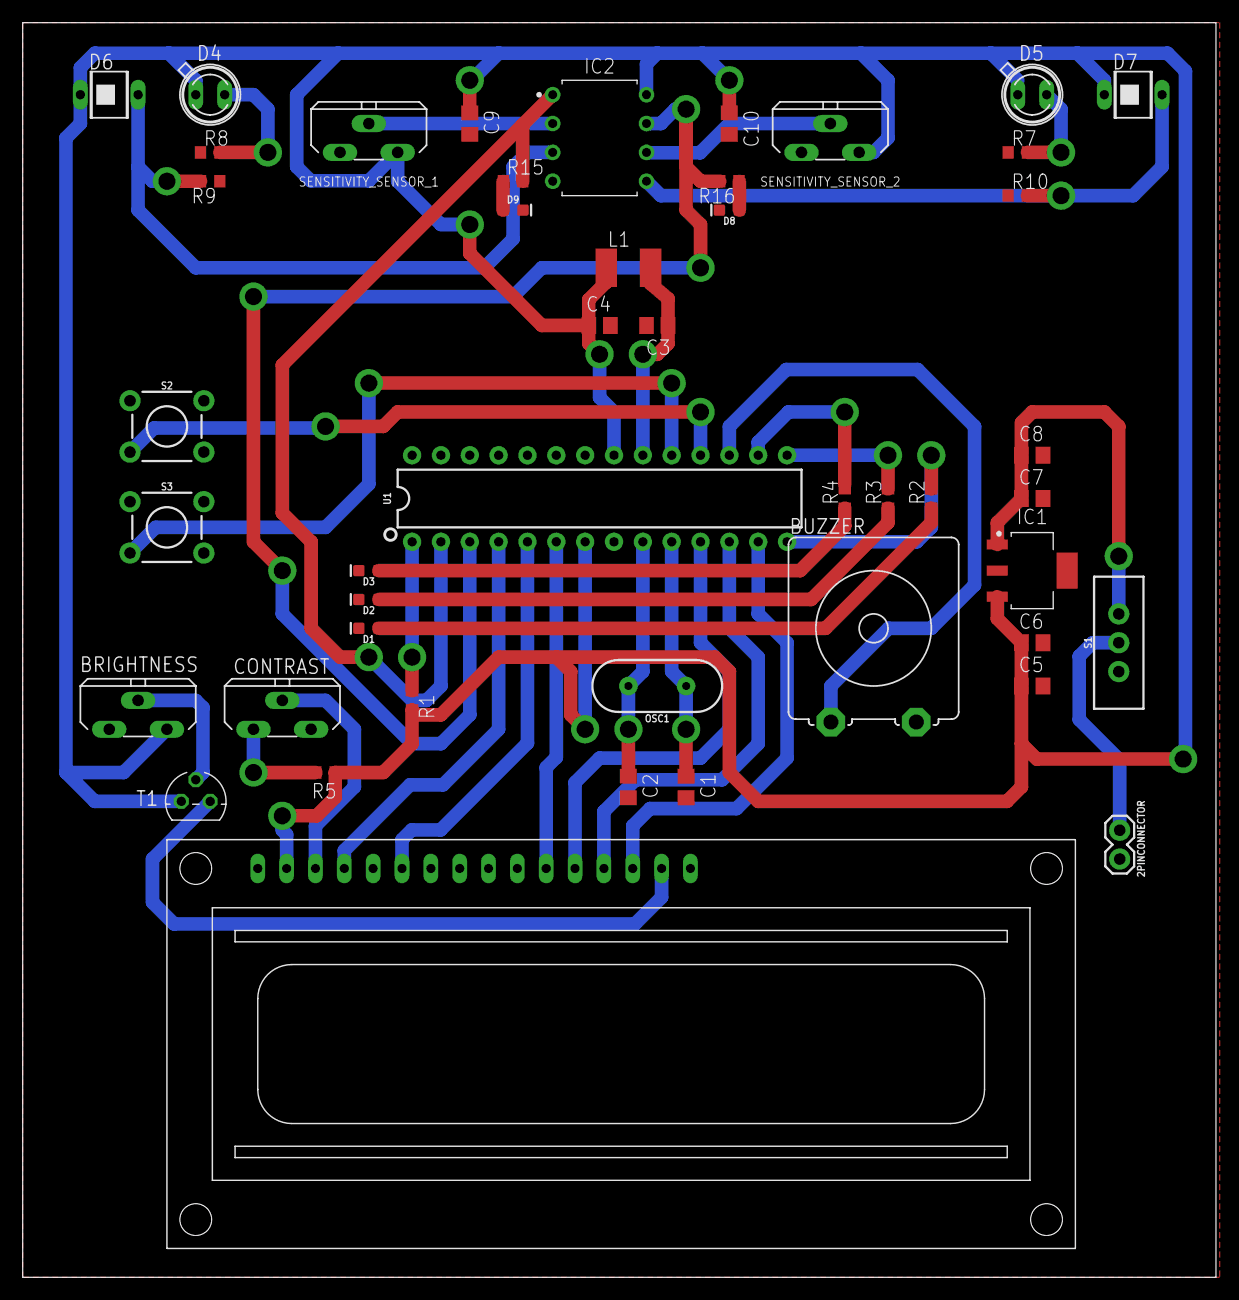
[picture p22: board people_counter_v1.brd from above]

Board: 2 copper layers, 105.1 x 110.5 mm, 46 parts (0 on the bottom side), 37 nets.

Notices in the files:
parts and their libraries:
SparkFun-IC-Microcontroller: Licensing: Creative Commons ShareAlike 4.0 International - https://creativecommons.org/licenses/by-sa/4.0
